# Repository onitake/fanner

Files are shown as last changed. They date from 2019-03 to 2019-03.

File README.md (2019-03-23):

# fanner

Simple, microcontroller-based PWM fan controller.

Has customizable temperature and PWM ranges.

## Requirements

* make
* avr-libc
* avr-gcc
* KiCAD 4+

## Software

### Customize

Open fanner.c in a text editor and adapt the parameters near the top.

The predefined voltages are optimized for the MCP-7900 temperature sensor.

PWM output values depend on the FAN used and require some experimentation.

### Build

```bash
make
```

### Flash

```
make flash
```

### Code

The code heavily relies on compile-time optimiziation and precalculation
of the (linear) transfer function coefficients.

At runtime, only 16-bit multiplication and addition is used to transform
the the values sampled by the AD converter into PWM output values.

The transfer function is a very simple piecewise linear curve, represented
by the formula:

    Sd      := (Dhigh - Dlow) / (Thigh - Tlow)
    ADClow  := ADC(Tlow) = (Tlow * Ss + Vofs) / Vref * ADCmax
    ADChigh := ADC(Thigh) = (Thigh * Ss + Vofs) / Vref * ADCmax
    D(ADC)  := ADC <= ADClow          : Dlow
               ADC >= ADChigh         : Dhigh
               ADClow < ADC < ADChigh : [Vref / ADCmax / Ss * Sd] - [Vofs / Ss * Sd]

Where:

    D    : Output duty cycle (Dlow and Dhigh are the flat parts of the curve) [%]
    Vref : Sensor reference voltage (the voltage corresponding to ADCmax) [V]
    ADC  : Input value from AD converter (ADClow and ADChigh are the values at
           lowest and highest temperatures on the transfer curve, respectively;
           ADCmax is the value generated when reference voltage is measured) [1]
    T    : Sensor temperature (with Tlow and Thigh corresponding to the Dlow
           and Dhigh duty cycle values) [°C]
    Ss   : Sensor voltage slope [V/°C]
    Vofs : Sensor offset voltage (voltage at lowest temperature) [V]
    Sd   : Output slope [%/°C]

To reduce sudden jumps in fan speed, a ramping function is used. The RAMP_DELTA
and RAMP_DELAY parameters allow for tuning the ramping speed.

## Electronics

### Design

Use KiCAD version 4 or later.

The board layout is based on THT components for easier building. And because
I had the components lying around in my workshop.

If you want the board in SMD, you have to design it yourself.

### Circuit

The circuit is really simple and just consists of a small microcontroller
(the ATtiny13/A), a voltage regulator (fans usually run on 12V) and some
pin headers for connecting the sensor, power and the fan.

The button and the corresponding pull-up resistor as well as the debouncing
capacitor are optional and currently not used in the example code.

## Copyright

© 2018-2019 Gregor Riepl

PCB designs and schematics are licensed under the CERN Open Hardware License 1.2.
Program code and build scripts are licensed under the Simplified BSD License.

See the accompanying LICENSE-HARDWARE and LICENSE-SOFTWARE files for details.

All other rights are reserved.

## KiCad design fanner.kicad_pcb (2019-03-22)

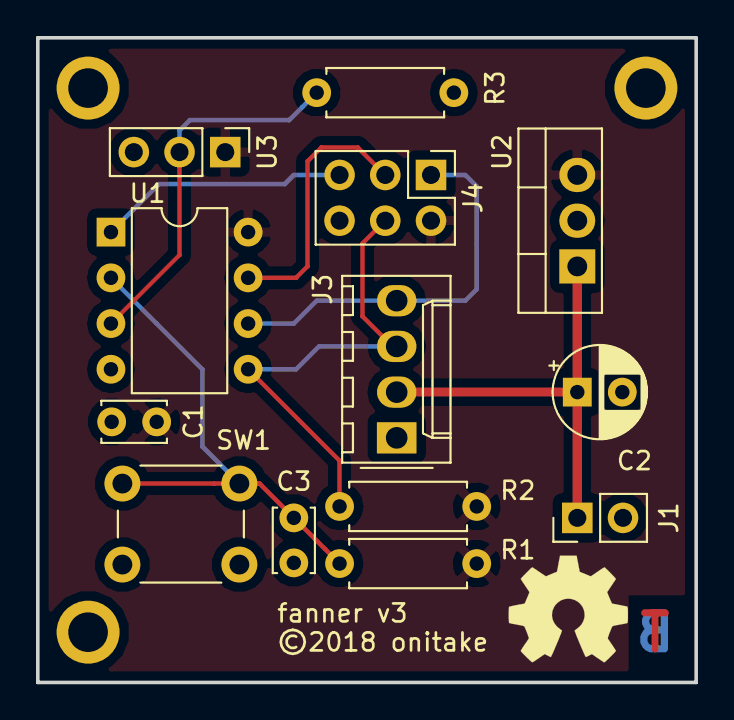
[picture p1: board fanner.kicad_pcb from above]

Board: 2 copper layers, 36.6 x 35.8 mm, 16 parts (0 on the bottom side), 9 nets.

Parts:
C1: 100n; C_Disc_D3.4mm_W2.1mm_P2.50mm
C2: 10u; CP_Radial_D5.0mm_P2.50mm
C3: 10n; C_Disc_D3.4mm_W2.1mm_P2.50mm
J1: 12V PWR; PinHeader_1x02_P2.54mm_Vertical
J3: PWM OUT; Molex_KK-254_AE-6410-04A_1x04_P2.54mm_Vertical
J4: ISP; PinHeader_2x03_P2.54mm_Vertical
MH1, MH2, MH3: -; MountingHole_2.2mm_M2_ISO7380_Pad
R1, R2, R3: 10k; R_Axial_DIN0207_L6.3mm_D2.5mm_P7.62mm_Horizontal
SW1: MODE; SW_PUSH_6mm
U1: ATtiny13A-PU; DIP-8_W7.62mm
U2: LM2937IMP-5.0; TO-220-3_Vertical
U3: MCP9700-ETO; PinHeader_1x03_P2.54mm_Vertical

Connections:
+5V: C1.1, J4.2, R1.1, R2.1, U1.8, U2.3, U3.1
+12V: C2.1, J1.1, J3.2, U2.1
/MISO: J3.4, J4.1, U1.6
/MOSI: J3.3, J4.4, R2.2, U1.5
/SCK: J4.3, U1.7
/TEMP: R3.1, U1.3, U3.2
/~RESET: J4.5, U1.1
GND: C1.2, C2.2, C3.2, J1.2, J3.1, J4.6, R3.2, SW1.2, U1.4, U2.2, U3.3
unnamed: C3.1, R1.2, SW1.1, U1.2

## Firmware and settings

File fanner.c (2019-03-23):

#include <stdint.h>
#include <avr/io.h>
#include <util/delay.h>

/*
pin configuration:
PB0 SENSE
PB1 PWM
PB3 SWITCH
PB4 TEMP
*/

/* max duty cycle change on each ramp steap */
#define RAMP_DELTA 1
/* delay between PWM updates (ms) */
#define RAMP_DELAY 10

/* reference voltage */
#define VOLTAGE_REF 5.0
/* sense voltage offset */
#define SENSE_OFFSET 0.5
/* sense voltage slope */
#define SENSE_SLOPE 0.01
/* ADC value at Vref */
#define ADC_MAX 255
/* lower temperature bound */
#define TEMP_LOW 20
/* upper temperature bound */
#define TEMP_HIGH 80
/* duty cycle at low bound */
#define DUTY_LOW 63
/* duty cycle at high bound */
#define DUTY_HIGH 255

/*
reference voltage: Vref : Vcc = 5V
sensor slope: Ss : 10mV/K
sensor offset: Vofs : 500mV
ADC range: ADC : ADCmin = 0 = 0V .. ADCmax = 255 = Vref
temperature range: T [°C] : Tmin = -50°C .. Tmax = 100°C
duty cycle: D : Dmin = 0 = 0% .. Dmax = 255 = 100%

mapping range temperature: T : Tlow = ? .. Thigh = ?
mapping range duty cycle: D : Dlow = ? .. Dhigh = ?

transfer curve: from linear to piecewise linear, clamped to low and high value
              _Thigh
            _/
          _/
        _/
      _/
Tlow_/
           ____Dhigh
          /
         /
Dlow____/ D(T)

D(T) := T <= Tlow : Dlow
        T >= Thigh : Dhigh
        Tlow < T < Thigh : T * Sd
output slope: Sd := (Dhigh - Dlow) / (Thigh - Tlow)

sensor voltage: Vs(T) := T * Ss + Vofs
T := (Vs - Vofs) / Ss
ADC output: ADC(T) := Vs / Vref * ADCmax
ADC(T) := (T * Ss + Vofs) / Vref * ADCmax
Vs(ADC) := ADC * Vref / ADCmax
T(ADC) := (Vref * ADC / ADCmax - Vofs) / Ss

ADClow := ADC(Tlow) = (Tlow * Ss + Vofs) / Vref * ADCmax
ADChigh := ADC(Thigh) = (Thigh * Ss + Vofs) / Vref * ADCmax
D(ADC) := 
  ADC <= ADClow : Dlow
  ADC >= ADChigh : Dhigh
  ADClow < ADC < ADChigh : T(ADC) * Sd =
    (Vref * ADC / ADCmax - Vofs) / Ss * Sd =
    ADC * [Vref / ADCmax / Ss * Sd] - [Vofs / Ss * Sd]
*/

/* Sd := (Dhigh - Dlow) / (Thigh - Tlow) */
#define DT_SLOPE ((double) DUTY_HIGH - (double) DUTY_LOW) / ((double) TEMP_HIGH - (double) TEMP_LOW)
/* D := ADC * MAD_M + MAD_A */
#define MAD_M ((double) VOLTAGE_REF / (double) ADC_MAX / (double) SENSE_SLOPE * (double) DT_SLOPE)
#define MAD_S ((double) SENSE_OFFSET / (double) SENSE_SLOPE * (double) DT_SLOPE)
/* same, 8+8bit for fixed point arithmetics */
#define MADS_M (uint16_t) (MAD_M * 255.0)
#define MADS_S (uint16_t) (MAD_S * 255.0)
/* ADClow := ADC(Tlow) = (Tlow * Ss + Vofs) / Vref * ADCmax */
#define ADC_LOW (uint8_t) ((TEMP_LOW * SENSE_SLOPE + SENSE_OFFSET) / VOLTAGE_REF * ADC_MAX)
/* ADChigh := ADC(Thigh) = (Thigh * Ss + Vofs) / Vref * ADCmax */
#define ADC_HIGH (uint8_t) ((TEMP_HIGH * SENSE_SLOPE + SENSE_OFFSET) / VOLTAGE_REF * ADC_MAX)

int main(void) __attribute__((noreturn));
static uint8_t ramp(uint8_t value, uint8_t target);
static void init(void);
static void hw_init(void);
static uint8_t scale(uint8_t adc);

struct {
	uint8_t ramp_current;
	uint8_t ramp_target;
} globals __attribute__((section(".noinit")));

uint8_t ramp(uint8_t current, uint8_t target) {
	if (current != target) {
		if (current > UINT8_MAX - RAMP_DELTA) {
			if (target > current) {
				return target;
			} else {
				if (current - RAMP_DELTA > target) {
					return current - RAMP_DELTA;
				} else {
					return target;
				}
			}
		} else if (current < 0 + RAMP_DELTA) {
			if (target < current) {
				return target;
			} else {
				if (current + RAMP_DELTA < target) {
					return current + RAMP_DELTA;
				} else {
					return target;
				}
			}
		} else {
			if (current + RAMP_DELTA < target) {
				return current + RAMP_DELTA;
			} else if (current - RAMP_DELTA > target) {
				return current - RAMP_DELTA;
			} else {
				return target;
			}
		}
	}
	return current;
}

void init(void) {
	globals.ramp_current = 0;
	globals.ramp_target = 0;
	
}

void hw_init(void) {
	/* set system clock to RC oscillator frequency / 1 (9.6MHz), overriding CKDIV8 */
	CLKPR = _BV(CLKPCE);
	CLKPR = 0;

	/* configure PD5 as PWM output */
	DDRB |= _BV(PB1);
	
	/* disable digital drivers on the analog comparator inputs */
	/*DIDR = _BV(AIN1D) | _BV(AIN0D);*/
	/* enable analog comparator */
	/*ACSR &= ~_BV(ACD);*/
	
	/* configure the ADC: Vcc reference, left adjust, ADC2/PB4 input */
	ADMUX = _BV(ADLAR) | _BV(MUX1);
	/* CPU clock = 9.6MHz / CLKDIV8 = 9.6MHz
	 * ADC clock < 200kHz => divider = 9.6MHz / 0.2MHz = 48
	 * divider = 64 => clock = 9.6MHz / 64 = 150kHz
	 * also enable auto mode. */
	ADCSRA = _BV(ADATE) | _BV(ADPS2) | _BV(ADPS1);
	/* set free running mode */
	ADCSRB &= ~(_BV(ADTS2) | _BV(ADTS1) | _BV(ADTS0));
	/* disable digital drivers on the analog input */
	DIDR0 &= ~_BV(ADC2D);
	/* enable the ADC and start converting */
	ADCSRA |= _BV(ADEN) | _BV(ADSC);
	/* the ADC will take 25 cycles (~167us) to finish the first conversion */
	_delay_us(200);
	
	/* enable PWM generator: fast PWM, 0..0xff, clear on match, set at TOP */
	OCR0B = 0;
	TCCR0A = _BV(COM0B1) | _BV(WGM01) | _BV(WGM00);
	/* clock select: CS[2:0]=001 -> CLK / 1 / PWMmax = 9.6MHz / 1 / 255 = 37.6kHz */
	TCCR0B = _BV(CS00);
}

uint8_t scale(uint8_t adc) {
	if (adc <= ADC_LOW) {
		return DUTY_LOW;
	} else if (adc >= ADC_HIGH) {
		return DUTY_HIGH;
	} else {
		uint16_t s = (uint16_t) adc * MADS_M - MADS_S;
		return (uint8_t) (s / 256);
	}
}

int main(void) {
	init();
	hw_init();
	
	while (1) {
		/* wait a jiffy between updates */
		_delay_ms(RAMP_DELAY);
		/* measure the temperature sensor voltage (only the top-most 8 bits) */
		uint8_t adc = ADCH;
		globals.ramp_target = scale(adc);
		/* ramp up or down */
		globals.ramp_current = ramp(globals.ramp_current, globals.ramp_target);
		/* set PWM value */
		OCR0B = globals.ramp_current;
	}
}

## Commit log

2019-03-22 Initial version
    [fanner.kicad_pcb, fanner.sch]
2019-03-23 Corrected some typos and added missing formula
    [fanner.c]

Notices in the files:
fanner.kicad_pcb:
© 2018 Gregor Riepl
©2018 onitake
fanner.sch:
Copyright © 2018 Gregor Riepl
